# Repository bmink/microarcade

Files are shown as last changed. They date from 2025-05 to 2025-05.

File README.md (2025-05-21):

Demo of microarcade

# microarcade

A tiny gaming console with 1-bit graphics and rotary encoders. It is built
from cheap components and the firmware is written completely from scratch (no
3rd party libraries).

## Why rotary encoders?

They're my favorite input devices for small builds. They take up very little
space yet allow you to do just about any type of input. I have long wondered
whether it would be fun to build and play a small console that uses two
rotary encoders for its input, supporting both single- and multi-user play.
(Verdict: it is!)

## Why no 3rd party libraries?

To be clear, we are not talking about bare metal. `microarcade` is based on
ESP32 and so is built using `esp-idf`, and runs on `FreeRTOS`. I'm only
talking about code to talk to the connected peripherals...

The two main types of peripherals the MCU interfaces with are the OLED display
and the rotary encoders. (There is also a separate clock module but that is
very simple to interface with using i2c).

* Rotary encoders are quite simple devices, but it is a surprisingly challenging
(and interesting) problem to build a driver for them that stands up to the
rigors of gaming. Most drivers out there are actually not that accurate in
terms of counting and will lose steps if you turn them fast as well as are
prone to other problems as well. For more information on this, check out
[esp_rotary](https://github.com/bmink/esp_rotary) which is my rotary encoder
driver for esp-idf.

* In the case of the display, I looked into several of the existing popular
graphics display code (eg. `Adafruit-GFX`, `U8g2`) but was surprised by how
inefficiently implemented they are and yet how cumbersome their APIs are. If
you instrument their code to log the commands they send to the display, you
will be able to observe this: for example, data transfers are unnecessarily
broken up into several transactions and many more commands are sent that would
actually be necessary. All in all, many more bytes are transferred over the
wire than would be necessary and that many times per second... it all would
add up and reduce per-frame CPU budget during gameplay. So I decided to
write my own efficient routines.

## Parts list

* 1x [ESP32-S3](https://a.co/d/aNbB3Xg)
* 1x [OLED](https://a.co/d/eaWpX4F) -- use the SPI version
* 2x [Rotary encoder](https://a.co/d/dhtsNsp)
* 1x [RTC](https://a.co/d/ggVVWnh)
* 1x [Panel-mount USB C socket](https://a.co/d/aPcbE0N) - use "Screw Nut Mount Type"
* 1x [4-pin right-angle USB C cable](https://a.co/d/cTP49Ir)

The reason there's a separate clock module is that I wanted `microarcade` to be
able to function as a desktop clock as well so I needed something that can
keep time when the device has no power.

## Wiring diagram

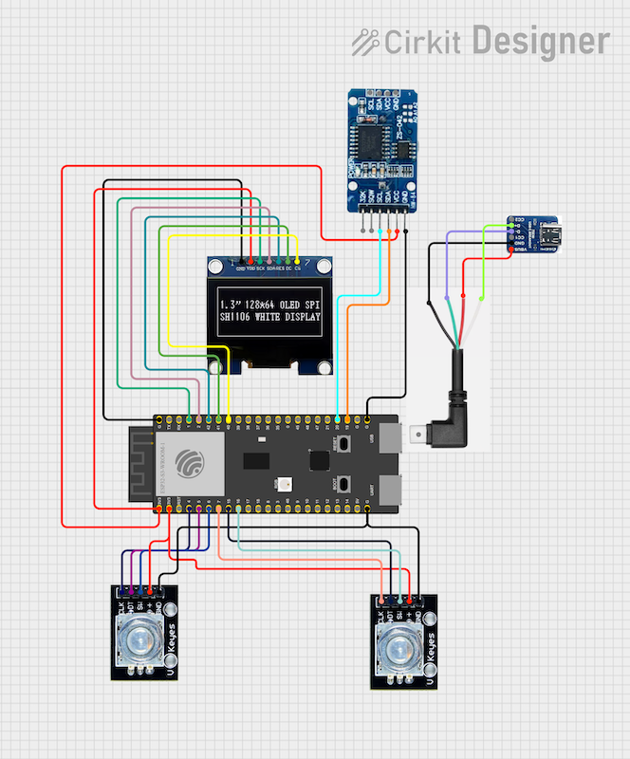
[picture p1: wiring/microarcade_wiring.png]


Wiring is quite simple -- everything is hooked up to
gpios / 3.3V / common as appropriate.

There is no battery in the current design, just a USB-C socket. I always have a
power source around so I didn't find it necessary to add a dedicated battery,
and this allows the enclosure to be extra small and lightweight.  Additionally,
having the USB socket on the enclosure go directy into the esp32's USB input
allows me to easily flash new code without needing to open the enclosure or
to add additional sockets. That said, a rechargeable battery could be added
quite easily.

## Enclosure

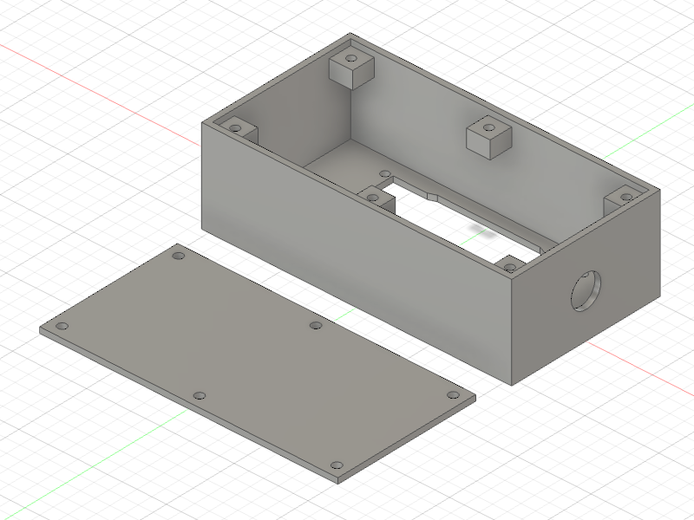
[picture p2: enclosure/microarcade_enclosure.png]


The enclosure is 3D printed to fit the specified parts exactly.
Fusion 360, BambuLab and STL files are provided in the
[enclosure folder](enclosure/).

Tips:
* I print my enclosures using plain matte PLA filament
* It's a good idea to enable "support" in the slicer for the screw tabs
* The display should be attached to the enclosure using M2.5 screws and nuts.
* The screw holes for the lid are sized for M3 screws. They will tap their
own thread as you screw them in for the first time. Do not overtighten.

# Notes on the firmware / Writing modules (applications)

## The Graphics Engine

### Framebuffers

Once a module's start function is called by the main menu, the module is given
complete control over the console, including the display, until it returns.

Graphics are done by drawing into a framebuffer, ie. a memory buffer that
represents the contents of the screen. In the case of `microarcade`, the
display is 128x64 pixels, and each pixel can be represented by one bit
(pixel on/off) so the framebuffer is 1024 bytes large (128 * 64 / 8). Once the
app finishes drawing the frame, it instructs the graphics engine to send
it to the display. Data is sent using DMA so the application doesn't have to
wait for it to complete but can go about doing other things. More detail
on all this later...

To eliminate the need for data conversions when transmitting to the display,
in-memory framebuffer bit mapping follows that of the SSD1309 display
controller, and is *vertical*. This means that one byte of framebuffer data
represents a one-pixel-wide by 8-pixels-tall section of the screen.
In most cases, applications don't have to worry about this since they won't
set bits in the framebuffer direcly, but instead use one of the drawing
functions provided, which all support vertical bit mapping.

### Sprites, tilemaps, fonts/text, shapes

Efficient support for all these are supported, see `disp.h`.

`disp_blt()` is one of the most core functions in the engine and is used not
only to blit (overlay) sprites into a frame, but also called by most other
graphics functions. Whatever the application needs to draw that is not
supported by built-in functions -- if it can do so by using one or a few
`disp_blt()` calls, it will be fast.

Like the framebuffers, Sprite buffer data has to be vertically bitmapped. Check
out my CLI sprite & font editor/animator
[sprited](https://github.com/bmink/sprited) for creating your sprites. It can
also dump sprite data in C code syntax (horizontally or vertically mapped),
which can be copy and pasted straight into source files.

### The framebuffer pool

A module may want to allocate an internal copy of a framebuffer for efficiency.
For example, it may want to draw a static background into a framebuffer once
and then keep copying the contents of this framebuffer into the main
framebuffer before overlaying sprites.

A 1K framebuffer generally is too large to be put on the stack so these copies
will have to be allocated on the heap. To reduce the number of memory
allocations and potential heap fragmentation, a frame buffer pool is provided.
Applications can request a framebuffer using `disp_getframebuf()`.
Framebuffers are released by calling `disp_releaseframebuf()`. The size of the
framebuffer pool is limited (8 by default), so applications should take care
not to request & hold more than they absolutely need and they must
release all framebuffers before they exit.

## Display modes

As mentioned, applications are expected to draw into the frame buffer pointed to
by `curframe` using the provided drawing, sprite bliting and text printing
functions. Then they are expected to tell the engine to send this frame to
the display.

Two modes for sending frames to the display are supported:

### Ad-hoc mode

```C

#define EVENTSTRMAX	16

char eventstr[EVENTSTRMAX];
int eventcnt = 0;

disp_set_mode(DISP_MODE_ADHOC, 0);

while(1) {

	/* Draw into curframe */
	snprintf(evenstr, EVENTSTRMAX, "%d events", eventcnt);
	disp_puttext(curframe, eventstr, &myfont, 0, 0);

	/* Send to display */
	disp_sendswapcurframe();

	/* Wait until next event (however long) */
	wait_for_event();

	++eventcnt;	
}

```

In "ad-hoc mode", there is no timing requirement. The application draws and
sends frames as needed, e.g. when an event occurs. Many seconds can elapse
between screen updates. An example for ad-hoc mode is a menu. The display
doesn't need to be refreshed until and unless the user scrolls the selection
(or selects an item). A screen update is sent with `disp_sendswapcurframe()`.
This function will enqueue `curframe` for transfer to the display, swap the
`curframe` pointer for a new (empty) frame buffer, and immediately return. The
previous `curframe` will be transferred to the display by a separate task,
using DMA, so the application can pretty much immediately return to doing
whatever it needs to do next.

### FPS mode

```C

#define BAR_MAXWIDTH 100

int barwidth = 0;
int inc = 1;

disp_set_mode(DISP_MODE_FPS, 15);	/* 15 frames per second */

while(1) {

	/* Draw into curframe */
	disp_drawbox(curframe, 0, 0, barwidth, 10, DISP_DRAW_ON);

	barwidth += inc;
	if(barwidth == BAR_MAXWIDTH)
		inc = -1;
	else
	if(barwidth == 0)
		inc = 1;

	/* Sleep until it's time to send this frame, then send to display */
	disp_sleep_sendswapcurframe();
}

```

In "FPS mode", the application first lets the graphics engine know at what
rate the display should be refreshed. This will prompt the engine to do some
internal time calculations to set up FPS mode. The application then is
responsible for redrawing the screen and enqueuing it for sending at the rate
it previously specified. It does so by calling `sleep_sendswapcurframe()`.
This function is identical to `sendswapcurframe()`, but first it delays
however long it has to to keep the FPS rate. In other words, as long as the
application is faster than the FPS rate, it can use `sleep_sendswapcurframe()`
to keep in sync with the FPS rate. Should the application take too much
time in drawing a frame, the next call of `sleep_sendswapcurframe()` will
drop the frame and make a note of this. (The internal variable
`disp_dropped_framecnt` can be queried for the number of times a frame
was dropped.)

## DMA

Frame data is sent to the display using DMA to offload this work from the
CPU, though this may not be immediately obvious when looking at the code.
The call used to transmit data is `spi_device_transmit()`. This call will
block until the transaction is complete, but under the hood, it does use
DMA (if the driver was configured to do so, which the engine does). This
becomes clear when we examine the source code of `esp-idf`:

Internally, `spi_device_transmit()` calls `spi_device_queue_trans()` followed
by `spi_device_get_trans_result()`. `spi_device_queue_trans()` enqueues the
transaction via DMA, and `spi_device_get_trans_result()` blocks until the
transaction finishes. The reason this works for us is that the graphics
engine's frame sender loop is in its own task. After the transaction is
enqueued, `spi_device_get_trans_result()` will block on a queue internal to the
SPI driver, ie. it will yield to the scheduler to run other tasks (such as the
code to generate the next frame).

As always with DMA, care must be taken to not access a buffer that is being
used by DMA is not being accessed until the transaction finished, this is
accomplished by the ping-pong frame technique accomplished by the "swap" part
of `sendswapcurframe()`. When an app call this function, `curframe` will be
swapped for a new empty framebuffer to continue drawing into, while the "old"
frame will be sent to the display.

# The local context

`microarcade` is a collection of menus and modules. Menus will call modules
(games) and modules themselves will display their own menus at times.
Whenever such a switch occurs, the callee will very likely change things like
display mode, display refresh rate (fps) and rotary configuration.

It such cases it is up to the callee to restore all settings to the way it
found them when it was called. The `local_context_t` struct and the
associated functions `save_lcontext()` and `restore_lcontext()` are provided
to make this task easy.

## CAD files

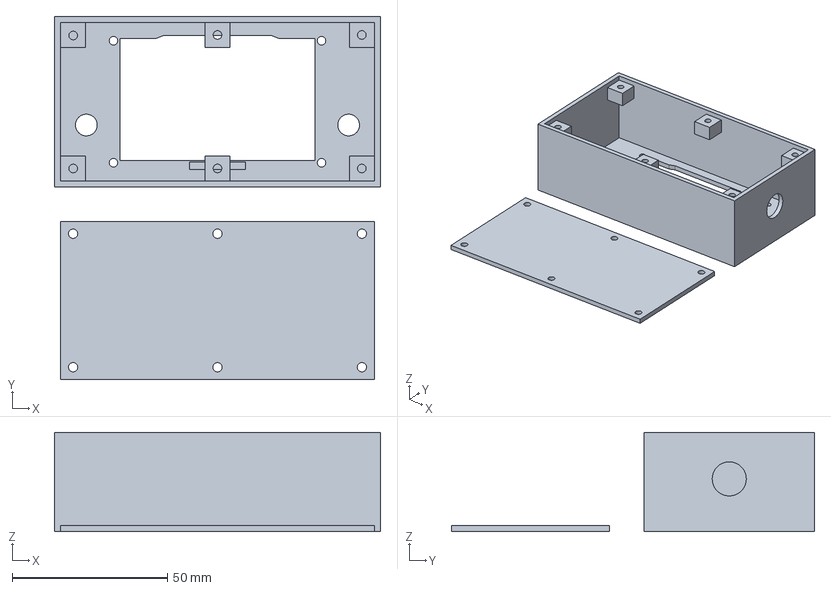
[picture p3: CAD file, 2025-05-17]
enclosure/microarcade.3mf
105.0 x 117.0 x 32.0 mm

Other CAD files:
enclosure/microarcade.f3d
enclosure/microarcade.stl

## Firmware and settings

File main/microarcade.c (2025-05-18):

#include <string.h>
#include <math.h>
#include <stdlib.h>
#include "freertos/FreeRTOS.h"
#include "freertos/task.h"
#include "driver/gpio.h"
#include "driver/spi_master.h"
#include "esp_check.h"
#include "esp_rotary.h"
#include "font.h"
#include "font_c64.h"
#include "font_picopixel.h"
#include "microarcade.h"
#include "disp.h"
#include "ui_menu.h"

static const char *ltag = "microarcade";

#define GPIO_BLINK	2

uint8_t	ball_buf[8] = {
	/* "ball" (8x8): vertical mapping, 64 pixels, 8 bytes */
	   0x3c, 0x7e, 0xff, 0xff, 0xff, 0xff, 0x7e, 0x3c };


typedef struct ball {
	int16_t	xpos;
	int16_t	ypos;
	int8_t	xvel;
	int8_t	yvel;
} ball_t;


#define MAX_BALLCNT 50
ball_t balls[MAX_BALLCNT] = { 0 };
int ballcnt = 10;

void mod_rotarytest_start(void);
void mod_pong_start(void);
void mod_asteroidbelt_start(void);


#define MAIN_MENU_ITEMCNT	2


ui_menu_item_t	main_menu[] = {

	{ "Rotary Test", MIT_CALLFUNC, mod_rotarytest_start, 0, NULL },
	{ "Gfx Perf Test", MIT_NONE, NULL, 0, NULL },
	{ "Pong", MIT_CALLFUNC, mod_pong_start, 0, NULL },
	{ "Etch-a-sketch", MIT_NONE, NULL, 0, NULL },
	{ "Clock", MIT_NONE, NULL, 0, NULL },
	{ "Asteroid Belt", MIT_CALLFUNC, mod_asteroidbelt_start, 0, NULL },
	{ "Lander", MIT_NONE, NULL, 0, NULL },
	{ "Minesweeper", MIT_NONE, NULL, 0, NULL },
	{ "Test1", MIT_NONE, NULL, 0, NULL },
	{ "Test2", MIT_NONE, NULL, 0, NULL },
	{ "Test3", MIT_NONE, NULL, 0, NULL },
	{ "Test4", MIT_NONE, NULL, 0, NULL },
	{ "Test5", MIT_NONE, NULL, 0, NULL },
	{  NULL }
};


#define MAIN_MENU_LINEMAXLEN	16
#define MAIN_MENU_MAXLINECNT	8


void splash(void);

void
app_main(void)
{
	esp_err_t			ret;
	gpio_config_t			gpioconf;
	rotary_config_t			rconf[ROTARY_CNT];
	disp_conf_t			dconf;

	ret = ESP_OK;

	/* Set up onboard LED -- will blink on error */
	memset(&gpioconf, 0, sizeof(gpio_config_t));

	gpioconf.mode = GPIO_MODE_OUTPUT;
	gpioconf.intr_type = GPIO_INTR_DISABLE;
	gpioconf.pin_bit_mask = 1ULL << GPIO_BLINK;
	ret = gpio_config(&gpioconf);
	if(ret != ESP_OK) {
		ESP_LOGE(ltag, "Could not config gpio\n");
		goto err_label;
		
	}

	/* Set up display */
	memset(&dconf, 0, sizeof(dconf));
	dconf.dc_pin_clk = 4;
	dconf.dc_pin_mosi = 5;
	dconf.dc_pin_reset = 6;
	dconf.dc_pin_dc = 7;
	dconf.dc_pin_cs = 15;
	dconf.dc_spi_hz = 10 * 1000 * 1000;

	ret = disp_init(&dconf);
	if(ret != ESP_OK)
		goto err_label;

	memset(rconf, 0, sizeof(rotary_config_t) * ROTARY_CNT);
	rconf[ROTARY_LEFT].rc_pin_a = 45;
	rconf[ROTARY_LEFT].rc_pin_b = 36;
	rconf[ROTARY_LEFT].rc_pin_button = 35;

	rconf[ROTARY_RIGHT].rc_pin_a = 21;
	rconf[ROTARY_RIGHT].rc_pin_b = 47;
	rconf[ROTARY_RIGHT].rc_pin_button = 20;

	if(rotary_config(rconf, ROTARY_CNT) != ESP_OK) {
		ESP_LOGE(ltag, "Could not configure rotary encoders\n");
		goto err_label;
	}

	/* Do splash screen only when first powered on */
	if(esp_reset_reason() == ESP_RST_POWERON)
		splash();

	ui_showmenu(main_menu, MAIN_MENU_MAXLINECNT, MAIN_MENU_LINEMAXLEN,
	    MENU_FULL_SCROLL);

	/* Not reached */
	ESP_LOGE(ltag, "Should not be here, main menu returned");

err_label:

	ESP_LOGE(ltag, "Error: %s\n", esp_err_to_name(ret));

	while (1) {
       		gpio_set_level(GPIO_BLINK, 0);
		vTaskDelay(pdMS_TO_TICKS(100));
		gpio_set_level(GPIO_BLINK, 1);
		vTaskDelay(pdMS_TO_TICKS(100));
	}
}

	
#if 0


int idx = 0;

int xpos = 25;
int ypos = 0;
int xspeed = 1;
int yspeed = 1;

srand((unsigned int)xTaskGetTickCount());

ballcnt = 10;
for(int i = 0; i < ballcnt; ++i) {
	balls[i].xvel = rand() % 6;
	balls[i].ypos = rand() % 50;
}

int ydirchange;
while(1) {
	
	memset(curframe, 0, 1024);

//	puttext("hello, world", &font_c64, 0, 0);
//	puttext("hello, world", &font_picopixel, 0, 8);

	puttext("hello, world", &font_c64, ypos, 0);
	puttext("hello, world", &font_picopixel, 0, 50-ypos);

	blt(domy_buf[idx], 128, 32, xpos, ypos);
	
	xpos += xspeed;
	ypos += yspeed;
	
	if((xspeed > 0 && xpos >= 128 - 32) ||
	    (xspeed < 0 && xpos <= 0))
		xspeed = -xspeed;

	if((yspeed > 0 && ypos >= 64 - 32) ||
	    (yspeed < 0 && ypos <= 0)) {
		yspeed = -yspeed; 
	}

	for(int i = 0; i < ballcnt; ++i) {
		ball_t *b = &balls[i];
		b->xpos += b->xvel;
		if(b->xpos > 120) {
			b->xpos = 120 - (b->xpos - 120);
			b->xvel = -b->xvel;
		} else
		if(b->xpos < 0) {
			b->xpos = -b->xpos;
			b->xvel = -b->xvel;
		}
			


		ydirchange = 0;
		b->ypos += b->yvel;
		if(b->ypos >= 56) {
//			b->ypos = 56 - (b->ypos - 56) * .7;
			b->ypos = 56;
//printf("old yvel=%d\n", b->yvel);
			b->yvel = -b->yvel * .8;
//			b->yvel = -b->yvel * .6;
//printf("new yvel=%d\n", b->yvel);
			++ydirchange;
			if(abs(b->yvel) < 2) {
				b->ypos = 0;
				b->xpos = 0;
				b->xvel = rand() % 20;
				b->yvel = 0;
			}
		}

		blt(ball_buf, 8, 8, b->xpos, b->ypos);

		if(!ydirchange)
			b->yvel += 2;
//printf("yvel=%d, ypos=%d\n", b->yvel, b->ypos);
	}

	memset(&transact, 0, sizeof(spi_transaction_t));
	transact.length = 1024 * 8;
	transact.tx_buffer = curframe;
	ret = spi_device_transmit(devhand, &transact);
	if(ret != ESP_OK) {
		printf("Could not send data\n");
		goto err_label;
	}


	vTaskDelay(pdMS_TO_TICKS(100));
	++idx;
	if(idx > 23)
		idx = 0;
}




#endif

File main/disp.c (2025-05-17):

#include <string.h>
#include "esp_log.h"
#include "freertos/FreeRTOS.h"
#include "freertos/task.h"
#include "driver/gpio.h"
#include "driver/spi_master.h"
#include "disp.h"

static const char *ltag = "disp";	/* Tag for logging */

static spi_device_handle_t	     devhand;
static disp_conf_t	dconf;


static uint8_t	frame1[FRAMESIZ]; /* Our ping-pong frames */
static uint8_t	frame2[FRAMESIZ];

uint8_t *curframe = frame1; /* The frame currently being drawn in */

static uint8_t	lframe[FRAMESIZ]; /* Last sent frame (ie. what's currently
				   * being displayed on the screen) */
uint8_t	*lastframe = lframe;

static SemaphoreHandle_t       sendframe_mutex;
static uint8_t		*sendframe = NULL;

static TaskHandle_t	frame_sender_task;

#define DISP_ADHOC_SENDTRY_WAITMS 10

static disp_mode_t disp_mode = DISP_MODE_ADHOC;
static int disp_fps;

static int disp_ticks_per_frame;
static TickType_t disp_last_frame_at;

int disp_dropped_framecnt = 0;

#define FRAMEBUDGET_RAVG_CNT	1000
/* Circular buffer of tick budget (ie. the remaining ticks we had left over
 * per frame) to calculate running average. */
uint32_t framebudget_val[FRAMEBUDGET_RAVG_CNT];
uint32_t framebudget_cur_idx;
uint32_t framebudget_cnt;
uint32_t framebudget_sum;



#define MAX_FPS		100

void
disp_set_mode(disp_mode_t newmode, int fps)
{

	switch(newmode) {
	case DISP_MODE_ADHOC:
		disp_fps = 0;
		disp_ticks_per_frame = 0;

		break;

	case DISP_MODE_FPS:
		disp_fps = fps;

		if(disp_fps >= MAX_FPS)
			disp_fps = MAX_FPS;

		disp_ticks_per_frame = pdMS_TO_TICKS(1000 / disp_fps);
		disp_last_frame_at = xTaskGetTickCount();

		break;
	}
	
	disp_mode = newmode;
}


static void
config_gpio(int pinnr)
{
        gpio_config_t   config;
        int             ret;

        memset(&config, 0, sizeof(gpio_config_t));

        config.mode = GPIO_MODE_OUTPUT;
        config.intr_type = GPIO_INTR_DISABLE;
        config.pin_bit_mask = 1ULL << pinnr;

        ret = gpio_config(&config);
        if(ret != ESP_OK)
                ESP_LOGE(ltag, "Could not config gpio %d", pinnr);
}


static int
sendspi(uint8_t *buf, uint32_t bufsiz)
{
	spi_transaction_t	transact;
	int			ret;

	memset(&transact, 0, sizeof(spi_transaction_t));
	transact.tx_buffer = buf;
	transact.length =  bufsiz * 8;

	ret = spi_device_transmit(devhand, &transact);
	if(ret != ESP_OK) {
		ESP_LOGE(ltag, "Could not send data on SPI");
	}

	return ret;
}


static void
frame_sender_loop(void *arg)
{
	int			had_frame_to_send;

	while(ulTaskNotifyTake(pdTRUE, portMAX_DELAY)) {
		had_frame_to_send = 0;
		xSemaphoreTake(sendframe_mutex, portMAX_DELAY);
		if(sendframe == NULL) {
			goto next_iter;
		}

		/* Only we can set sendframe back to NULL, and the writer
		 * will not notify as long as it it not NULL, so
		 * it's safe to release the mutex here */
		xSemaphoreGive(sendframe_mutex);

		sendspi(sendframe, FRAMESIZ);

		++had_frame_to_send;	
		xSemaphoreTake(sendframe_mutex, portMAX_DELAY);
		sendframe = NULL;

next_iter:
		xSemaphoreGive(sendframe_mutex);

		if(!had_frame_to_send)
			ESP_LOGE(ltag, "Was woken up but nothing to send!\n");
		
	}
	
}


void
disp_clearcurframe(void)
{
	memset(curframe, 0, FRAMESIZ);
}


void
disp_sendswapcurframe(void)
{
	xSemaphoreTake(sendframe_mutex, portMAX_DELAY);

	if(sendframe != NULL) {
		if(disp_mode == DISP_MODE_FPS) {

			/* We are in fps mode. Frame has to be dropped */

			ESP_LOGE(ltag, "Dropping frame!\n");
			++disp_dropped_framecnt;
			goto end_label;

		} else { /* DISP_MODE_ADHOC */

			/* We are in ad-hoc / slow update mode. Wait until
			 * sendframe is clear and send our frame */

			while(sendframe != NULL) {
				xSemaphoreGive(sendframe_mutex);
				vTaskDelay(pdMS_TO_TICKS(
				    DISP_ADHOC_SENDTRY_WAITMS));
				xSemaphoreTake(sendframe_mutex, portMAX_DELAY);
			}
		}
	}

	sendframe = curframe;
	if(curframe == frame1)
		curframe = frame2;
	else
		curframe = frame1;

	memcpy(lframe, sendframe, FRAMESIZ);

	xTaskNotifyGive(frame_sender_task);

end_label:
	xSemaphoreGive(sendframe_mutex);
	disp_clearcurframe();
}


void
disp_sleep_sendswapcurframe(void)
{

	vTaskDelayUntil(&disp_last_frame_at, disp_ticks_per_frame);

	disp_sendswapcurframe();
}


void
disp_blt(uint8_t *frame, uint8_t *buf, uint32_t buflen, int8_t spritewidth,
	int xpos, int ypos)
{
	/*
	 * Can safely be called with negative / out of bound xpos and ypos
	 * (sprites will be cut off)
	 */
	int	x;
	int	y;
	int	ybase;	
	int	ymod;	
	uint8_t	*framecur;
	uint8_t	*spritecur;
	int	i;
	uint8_t	byte;

	/* Screen buffer is vertically mapped so for y positions that aren't
	 * divisible by 8, we have to do some bit shifting */
		
	ybase = ypos / 8;
	ymod = ypos % 8;
	if(ypos < 0) {
		--ybase;
		ymod = 8 + ymod;
	}

	spritecur = buf;
	framecur = frame + FRAME_WIDTH * ybase + xpos;
	for(i = 0, x = xpos, y = ybase; i < buflen + spritewidth; ++i) {

		if(x >= 0 && x < FRAME_WIDTH && y >= 0 && y < 8) {

			if(i < buflen)
				byte = *spritecur << ymod;
			else	/* Overflow row */
				byte = 0;

			if(i >= spritewidth)
				byte |= *(spritecur - spritewidth) >>
				    (8 - ymod);

			*framecur |= byte;
		}

		++x;
		if(((i+1) % spritewidth) == 0) {
			x = xpos;
			++y;
			framecur = frame + FRAME_WIDTH * y + xpos;
		} else
			++framecur;

		++spritecur;
	}


}


int
disp_contactblt(uint8_t *frame, uint8_t *buf, uint32_t buflen,
	int8_t spritewidth, int xpos, int ypos)
{
	/*
	 * Same as disp_blt(), except doesn't overlay the sprite, but checks
	 * for contact with any previously drawn pixels in the frame.
	 * Returns 0 if the sprite does not contact anything, or nonzero
	 * if it does.
	 */
	int	x;
	int	y;
	int	ybase;	
	int	ymod;	
	uint8_t	*framecur;
	uint8_t	*spritecur;
	int	i;
	uint8_t	byte;

	/* Screen buffer is vertically mapped so for y positions that aren't
	 * divisible by 8, we have to do some bit shifting */
		
	ybase = ypos / 8;
	ymod = ypos % 8;
	if(ypos < 0) {
		--ybase;
		ymod = 8 + ymod;
	}

	spritecur = buf;
	framecur = frame + FRAME_WIDTH * ybase + xpos;
	for(i = 0, x = xpos, y = ybase; i < buflen + spritewidth; ++i) {

		if(x >= 0 && x < FRAME_WIDTH && y >= 0 && y < 8) {

			if(i < buflen)
				byte = *spritecur << ymod;
			else	/* Overflow row */
				byte = 0;

			if(i >= spritewidth)
				byte |= *(spritecur - spritewidth) >>
				    (8 - ymod);

			if(*framecur & byte)
				return 1;
		}

		++x;
		if(((i+1) % spritewidth) == 0) {
			x = xpos;
			++y;
			framecur = frame + FRAME_WIDTH * y + xpos;
		} else
			++framecur;

		++spritecur;
	}

	return 0;
}
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

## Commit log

2025-04-28 Adding menu and separate frame sending task
2025-05-07 Enclosure files
    [microarcade.3mf, microarcade.f3d, microarcade.stl]
2025-05-13 Fix blt() to properly cut off at screen edge
    [disp.c]
2025-05-13 Adding back plate and lip around it
    [microarcade.3mf, microarcade.f3d, microarcade.stl]
2025-05-15 Asteroid Belt progress
    [microarcade.3mf, microarcade.f3d, microarcade.stl]
2025-05-15 Asteroid Belt sprites
2025-05-15 Better thrust graphics
2025-05-16 Wiring diagram
2025-05-17 Asteroid Belt updates
    [microarcade.3mf]
